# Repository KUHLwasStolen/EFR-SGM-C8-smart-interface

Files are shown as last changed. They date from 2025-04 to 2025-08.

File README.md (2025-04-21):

# EFR-SGM-C8-smart-interface
This project reads the SML-interface of the EFR-SGM-C8 energy meter via an ESP32 and then provides a local web server to show the extracted information.  
This is useful if your meter does not have the "smart" module installed, which net providers like to omit, because... money.  
You can then use the web server to conveniently check you energy usage and adjust the output of your solar storage to not waste any energy or give it away, helping you save even more money.  
Additionally, the API that the website uses to keep itself updated is also available for you to use in other projects.  

**Planned:** In the near future I would also like to add some logging capabilities to the project via an SD card module. This would allow us to display historic data on the website (last 24h/7d/30d/...) which the meter itself collects but does not provide via the IR-interface. Also the data can be used to generate some graphs.  

## Hardware
The project is designed around an ESP32 Mini development board and an TCRT5000 IR sensor.  
Additionally magnets are used to mount the project on the energy-meter.  
The links below are there to show visually you what I mean, not buying recommendations.  

Product | Link
-|-
ESP32 Mini dev board | https://www.az-delivery.de/en/products/esp32-d1-mini-nodemcu-wifi-modul-esp-32-bluetooth-internet-entwicklungsboard-mit-usb-c-anschluss-kompatibel-mit-arduino-und-ko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
TCRT5000 IR sensor | https://www.az-delivery.de/en/products/linienfolger-modul-mit-tcrt5000-und-analog-ausgang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
Round magnets with ~20 mm diameter | no link needed, very generic

Yes, it would also be possible to entirely skip the IR sensor and use only a photo-resistor.  
But I like that the sensor board comes with a potentiometer to easily adjust the sensitivity (which is very important!!!) and that it has an easily accessible mounting point.  

## Installation
### Software
Flashing the ESP with the program should be pretty straightforward:  
1. Clone the repository to your computer
2. Now you need to configure the project. In an ESP-IDF terminal type `idf.py menuconfig`, do your basic setup and go to the menu `YOUR CONFIGURATION` and enter your information there (WiFi config, timezone). To select the correct time zone you can refer to the column on the right of [this](https://github.com/nayarsystems/posix_tz_db/blob/master/zones.csv) list. Make sure that your entries **only** contain the information that their name indicates with **no** additional spaces or other characters before and after your entry, so the ESP can find your WiFi and understand your timezone.
3. Build and flash the project with ESP-IDF.

### Hardware
The hardware setup is also very simple.  
You only need to supply the IR sensor with 3.3V and GND and you need to connect pin 16 of the ESP with the digital out pin of the sensor.  
Now you only need to assemble the 3D-print and mount it on your energy-meter (see below).  

## CAD/3D-models
Currently the only model available is the sensor mount itself. It is already oriented in the intended printing position and does require some supports for the top hook.  
Soon I will add a cover for the mount which also includes an SD card reader spot.  

## Note on the website files
Excuse the weird/lack-of formatting in all of the HTML/CSS/JS files. As they are copied 1-to-1 to the ESP's flash I am trying to save a bit of file size by reducing the readability-formatting to a minimum. If you want, you can let your IDE format the files a bit more readably and then when done editing reduce to tab-size down to one or two spaces again.

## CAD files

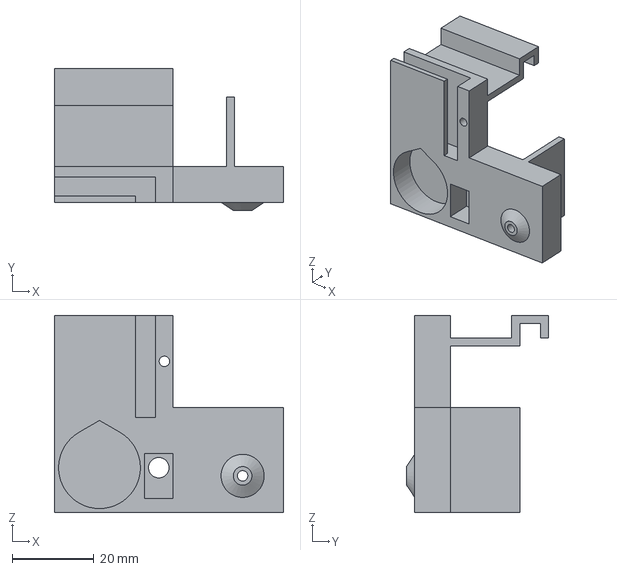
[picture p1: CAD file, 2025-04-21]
cad/exports/irReaderMount.step
56.0 x 34.8 x 48.2 mm

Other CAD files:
cad/sensorMountModels.FCStd

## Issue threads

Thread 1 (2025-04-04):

Meter readings inconsistency

KUHLwasStolen, 2025-04-04:
There is a weird inconsistency in the meter readings.
Not all messages with the correct ID for the meter readings (1.8.0 and 2.8.0) seem to carry the data.
But this is weird, because why send the messages at all then?

A possible explanation would be that my method of reading the data is faulty.
But why are the current power readings consistent and correct then? And why can I even detect the message ID if the data is faulty?

Currently obvious outliers are already filtered, but still some do make it through.
I have to be overseeing something here. Will collect more data logs and try to decipher what makes these wrong messages special.

***Update 1:*** I've now implemented decoding for 1.8.1, 1.8.2, 2.8.1 and 2.8.2 just to see if those values come through consistently. And they indeed do. I assume this means that there is nothing wrong with my physical setup nor my code.

This still doesn't explain why 1.8.0 and 2.8.0 are so weird, but at least we can cope with it now.

Some possible approaches:
1. Calculate the values: $1.8.0 = 1.8.1 + 1.8.2$ and $2.8.0 = 2.8.1 + 2.8.2$
Problem: Depending on your setup this might not work. My example: 1.8.1 and 1.8.2 are sent but 2.8.1 and 2.8.2 are only 0.
2. Let the user chose which of the several collected values are correct and then we can deduce which changes are realistic.
Problem: Requires user intervention, edge cases possible.
3. Collect the last x values and calculate the median over them. This should work as most of the time the correct data is sent. I will implement this and see if it works properly.

***Update 2:*** After implementing a hybrid of approaches 1 and 3 above, the issue is smoothed out a bit, but still not unnoticeable. I have also noticed that values for 1.8.1 and 1.8.2 do in fact not come through perfectly every time, but still better than 1.8.0 alone.

I have noticed that sometimes there are values which theoretically would be correct, but they are received for the wrong ID. This might suggest that there is some kind of bit flip issue going on(?).

For now at least this is my last idea: There is some physical issue going on in the system that sometimes causes a bit flip in the received data and for some reason some messages are easier affected than others (or maybe it's just more noticeable for them as for example wattage values change more often anyways(?)).

My next attempt at solving this will be to add a small resistor in line with the UART RX pin to reduce the noise on there a bit.

***Update 3:*** I have now realized that my implementation of inserting values into the median arrays was faulty and basically deactivated the median. I have now fixed it and, surprise, no faulty values make it through to the UI now...
The only thing that is left to do now is to tune the size of the median arrays in order to balance fault tolerance and responsiveness.
Also, I think we just have to accept that the IR transmission isn't perfect.
(Btw, adding resistors and even diodes to the signal line didn't fix the issues 😅 )

Closed 2025-04-12.

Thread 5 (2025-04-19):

Add smoothing to power draw

KUHLwasStolen, 2025-04-19:
I have noticed that the power values fluctuate quite a bit more than what is shown on the meter's display, which I guess boils down to the same problems as in #1
To fix this also add "median-smoothing" but with a smaller median array because these values need a bit more flexibility than the energy readings.

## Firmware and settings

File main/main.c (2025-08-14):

#include <stdio.h>
#include <stdlib.h>

#include "driver/gpio.h"
#include "driver/uart.h"
#include "soc/uart_channel.h"
#include "esp_log.h"
#include "freertos/FreeRTOS.h"
#include "freertos/task.h"
#include "esp_system.h"

#include "esp_http_server.h"
#include "esp_wifi.h"
#include "esp_event.h"
#include "nvs_flash.h"
#include "esp_netif_sntp.h"
#include "esp_sntp.h"
#include "cJSON.h"

#define WIFI_MAXIMUM_RETRY 5
uint8_t wifi_retries = 0;

#define WIFI_CONNECTED_BIT BIT0
#define WIFI_FAIL_BIT      BIT1

httpd_handle_t serverHandle = NULL;
static EventGroupHandle_t s_wifi_event_group;

void insertFloatAtFirstIndex(float* arr, uint16_t len, float value);
void insertI32AtFirstIndex(int32_t* arr, uint16_t len, int32_t value);
float medianFloat(float* arr, uint16_t len);
int32_t medianI32(int32_t* arr, uint16_t len);
int compareFloat(const void* f1, const void* f2);
int compareI32(const void* i1, const void* i2);
void addFloatToMedianArr(float* arr, uint8_t* sizeCounter, uint8_t sizeMax, float value);
void addI32ToMedianArr(int32_t* arr, uint8_t* sizeCounter, uint8_t sizeMax, int32_t value);

extern const uint8_t indexHtmlFile[] asm("_binary_index_html_start");
extern const uint8_t stylesCssFile[] asm("_binary_styles_css_start");
extern const uint8_t updaterJsFile[] asm("_binary_updater_js_start");
extern const uint8_t settingsHtmlFile[] asm("_binary_settings_html_start");
extern const uint8_t settingsJsFile[] asm("_binary_settings_js_start");
extern const uint8_t faviconSVG_start[] asm("_binary_favicon_svg_start");
extern const uint8_t faviconSVG_end[] asm("_binary_favicon_svg_end");

typedef struct settings_t {
    float importCost;
    float importCostT1;
    float importCostT2;
    float exportCost;
    float exportCostT1;
    float exportCostT2;
    char currency[8];
} settings_t;

int32_t currentPower = 0, currentPowerL1 = 0, currentPowerL2 = 0, currentPowerL3 = 0; // in W
float importOverall = 0.0f, importT1 = 0.0f, importT2 = 0.0f, exportOverall = 0.0f, exportT1 = 0.0f, exportT2 = 0.0f; // in kWh
settings_t settings = {0};

time_t upSince = 0;
char upSinceStr[64] = {};
struct tm timeinfo = {0};

// To decode the SML messages
static void irReaderTask(void* args) {
    const uart_port_t irUART = UART_GPIO16_DIRECT_CHANNEL;
    uart_config_t irConfig = {
        .baud_rate = 9600,
        .data_bits = UART_DATA_8_BITS,
        .parity = UART_PARITY_DISABLE,
        .stop_bits = UART_STOP_BITS_1,
        .flow_ctrl = UART_HW_FLOWCTRL_DISABLE,
        .source_clk = UART_SCLK_DEFAULT,
    };

    ESP_ERROR_CHECK(uart_param_config(irUART, &irConfig));
    ESP_ERROR_CHECK(uart_set_pin(irUART, UART_PIN_NO_CHANGE, 16, UART_PIN_NO_CHANGE, UART_PIN_NO_CHANGE));

    const int uart_buffer_size = 1200 * 2;
    QueueHandle_t uart_queue;

    ESP_ERROR_CHECK(uart_driver_install(irUART, uart_buffer_size, 0, 1, &uart_queue, 0));

    // All of these values are temporary and used by multiple code segments!!!
    // Only use them as placeholders for extracting information from the SML messages!!!
    uint8_t buffer[uart_buffer_size] = {};
    uint16_t readLength = 0;
    uint8_t valueID;
    uint8_t valueLength;
    uint8_t iOffset;
    int32_t tempPower;
    uint64_t meterReadRaw = 0;

    // defines how many values are saved at maximum, for the calculation of the median of the meter readings
    #define BIG_MEDIAN_SIZE_MAX 15
    float importMedianArr[BIG_MEDIAN_SIZE_MAX] = {};
    float importT1MedianArr[BIG_MEDIAN_SIZE_MAX] = {};
    float importT2MedianArr[BIG_MEDIAN_SIZE_MAX] = {};
    float exportMedianArr[BIG_MEDIAN_SIZE_MAX] = {};
    float exportT1MedianArr[BIG_MEDIAN_SIZE_MAX] = {};
    float exportT2MedianArr[BIG_MEDIAN_SIZE_MAX] = {};
    uint8_t importMedianSize = 0, importT1MedianSize = 0, importT2MedianSize = 0, exportMedianSize = 0, exportT1MedianSize = 0, exportT2MedianSize = 0;

    #define SMALL_MEDIAN_SIZE_MAX 5
    int32_t currentPowerMedianArr[SMALL_MEDIAN_SIZE_MAX] = {};
    int32_t currentPowerL1MedianArr[SMALL_MEDIAN_SIZE_MAX] = {};
    int32_t currentPowerL2MedianArr[SMALL_MEDIAN_SIZE_MAX] = {};
    int32_t currentPowerL3MedianArr[SMALL_MEDIAN_SIZE_MAX] = {};
    uint8_t currentPowerMedianSize = 0, currentPowerL1MedianSize = 0, currentPowerL2MedianSize = 0, currentPowerL3MedianSize = 0;

    while(1) {
        readLength = uart_read_bytes(irUART, buffer, uart_buffer_size - 1, 300 / portTICK_PERIOD_MS);

        if(readLength > 0) {
            ESP_LOGI("UART", "New Message (size: %u):", readLength);

            valueID = 0;
            valueLength = 0;

            for(uint16_t i = 0; i < readLength; i++) {
                // printf("%02X ", buffer[i]);

                // Power:           77 07 01 00 10 07 00 FF
                // L1:              77 07 01 00 24 07 00 FF
                // L2:              77 07 01 00 38 07 00 FF
                // L3:              77 07 01 00 4C 07 00 FF
                // Import overall:  77 07 01 00 01 08 00 FF
                // Import T1:       77 07 01 00 01 08 01 FF
                // Import T2:       77 07 01 00 01 08 02 FF
                // Export overall:  77 07 01 00 02 08 00 FF
                // Export T1:       77 07 01 00 02 08 01 FF
                // Export T2:       77 07 01 00 02 08 02 FF
                if(buffer[i] == 0x77) {
                    if(buffer[i+1] == 0x07) {
                        if(buffer[i+2] == 0x01) {
                            if(buffer[i+3] == 0x00) {
                                if(buffer[i+4] == 0x10 || buffer[i+4] == 0x24 || buffer[i+4] == 0x38 || buffer[i+4] == 0x4C) { // power values
                                    if(buffer[i+5] == 0x07) {
                                        if(buffer[i+6] == 0x00) {
                                            if(buffer[i+7] == 0xFF) {
                                                valueID = buffer[i+13];
                                                valueLength = ((uint8_t)(valueID << 4)) >> 4;
                                                tempPower = 0;

                                                if(valueLength == 0) {
                                                    valueID = buffer[i+14];
                                                    valueLength = ((uint8_t)(valueID << 4)) >> 4;
                                                    iOffset = 1;
                                                } else {
                                                    iOffset = 0;
                                                }
                                                
                                                switch(valueLength) {
                                                    case 2:
                                                        tempPower = (int32_t)(int8_t)buffer[i+14+iOffset];
                                                    break;

                                                    case 3:
                                                        tempPower = ((int32_t)((int8_t)buffer[i+14+iOffset]) << 8) + (uint32_t)buffer[i+15+iOffset];
                                                    break;

                                                    case 4:
                                                        tempPower = ((int32_t)((int8_t)buffer[i+14+iOffset]) << 16) + ((uint32_t)(buffer[i+15+iOffset]) << 8) + (uint32_t)buffer[i+16+iOffset];
                                                    break;

                                                    default:
                                                        ESP_LOGW("Parsing", "Unexpected value length: %d", valueLength);
                                                }

                                                switch(buffer[i+4]) {
                                                    case 0x10:
                                                        addI32ToMedianArr(currentPowerMedianArr, &currentPowerMedianSize, SMALL_MEDIAN_SIZE_MAX, tempPower);
                                                        currentPower = medianI32(currentPowerMedianArr, currentPowerMedianSize);
                                                    break;

                                                    case 0x24:
                                                        addI32ToMedianArr(currentPowerL1MedianArr, &currentPowerL1MedianSize, SMALL_MEDIAN_SIZE_MAX, tempPower);
                                                        currentPowerL1 = medianI32(currentPowerL1MedianArr, currentPowerL1MedianSize);
                                                    break;

                                                    case 0x38:
                                                        addI32ToMedianArr(currentPowerL2MedianArr, &currentPowerL2MedianSize, SMALL_MEDIAN_SIZE_MAX, tempPower);
                                                        currentPowerL2 = medianI32(currentPowerL2MedianArr, currentPowerL2MedianSize);
                                                    break;

                                                    case 0x4C:
                                                        addI32ToMedianArr(currentPowerL3MedianArr, &currentPowerL3MedianSize, SMALL_MEDIAN_SIZE_MAX, tempPower);
                                                        currentPowerL3 = medianI32(currentPowerL3MedianArr, currentPowerL3MedianSize);
                                                    break;
                                                }
                                            }
                                        }
                                    }
                                } else if(buffer[i+4] == 0x01 || buffer[i+4] == 0x02) { // import, export
                                    if(buffer[i+5] == 0x08) {
                                        if(buffer[i+6] == 0x00 || buffer[i+6] == 0x01 || buffer[i+6] == 0x02) {
                                            if(buffer[i+7] == 0xFF) {
                                                // search for 0x52FF
                                                for(uint16_t j = i+8; j < i+30; j++) {
                                                    if(buffer[j] == 0x52 && buffer[j+1] == 0xFF) {
                                                        meterReadRaw = 0;

                                                        // search for next message to determine value length
                                                        for(uint8_t k = 2; k < 6; k++) {
                                                            if(buffer[j+3+k] == 0x01 && buffer[j+3+k+1] == 0x77) {
                                                                if(k < 3) break;

                                                                // now fill meterReadRaw according to length
                                                                for(uint8_t l = 0; l < k; l++) {
                                                                    meterReadRaw += ((uint64_t)buffer[j+3+l]) << ((k-1-l)*8);
                                                                }

                                                                switch(buffer[i+4]) {
                                                                    case 0x01: // import
                                                                        switch(buffer[i+6]) {
                                                                            case 0x00:
                                                                                addFloatToMedianArr(importMedianArr, &importMedianSize, BIG_MEDIAN_SIZE_MAX, meterReadRaw / 10000.0f);
                                                                                importOverall = medianFloat(importMedianArr, importMedianSize);
                                                                            break;

                                                                            case 0x01:
                                                                                addFloatToMedianArr(importT1MedianArr, &importT1MedianSize, BIG_MEDIAN_SIZE_MAX, meterReadRaw / 10000.0f);
                                                                                importT1 = medianFloat(importT1MedianArr, importT1MedianSize);
                                                                                if(importT1 > 1 && importT2 > 1) addFloatToMedianArr(importMedianArr, &importMedianSize, BIG_MEDIAN_SIZE_MAX, importT1 + importT2);
                                                                            break;

                                                                            case 0x02:
                                                                                addFloatToMedianArr(importT2MedianArr, &importT2MedianSize, BIG_MEDIAN_SIZE_MAX, meterReadRaw / 10000.0f);
                                                                                importT2 = medianFloat(importT2MedianArr, importT2MedianSize);
                                                                                if(importT1 > 1 && importT2 > 1) addFloatToMedianArr(importMedianArr, &importMedianSize, BIG_MEDIAN_SIZE_MAX, importT1 + importT2);
                                                                            break;
                                                                        }
                                                                    break;

                                                                    case 0x02: // export
                                                                        switch(buffer[i+6]) {
                                                                            case 0x00:
                                                                                addFloatToMedianArr(exportMedianArr, &exportMedianSize, BIG_MEDIAN_SIZE_MAX, meterReadRaw / 10000.0f);
                                                                                exportOverall = medianFloat(exportMedianArr, exportMedianSize);
                                                                            break;

                                                                            case 0x01:
                                                                                addFloatToMedianArr(exportT1MedianArr, &exportT1MedianSize, BIG_MEDIAN_SIZE_MAX, meterReadRaw / 10000.0f);
                                                                                exportT1 = medianFloat(exportT1MedianArr, exportT1MedianSize);
                                                                                if(exportT1 > 1 && exportT2 > 1) addFloatToMedianArr(exportMedianArr, &exportMedianSize, BIG_MEDIAN_SIZE_MAX, exportT1 + exportT2);
                                                                            break;

                                                                            case 0x02:
                                                                                addFloatToMedianArr(exportT2MedianArr, &exportT2MedianSize, BIG_MEDIAN_SIZE_MAX, meterReadRaw / 10000.0f);
                                                                                exportT2 = medianFloat(exportT2MedianArr, exportT2MedianSize);
                                                                                if(exportT1 > 1 && exportT2 > 1) addFloatToMedianArr(exportMedianArr, &exportMedianSize, BIG_MEDIAN_SIZE_MAX, exportT1 + exportT2);
                                                                            break;
                                                                        }
                                                                    break;
                                                                }

                                                                break;
                                                            }
                                                        }

                                                        break;
                                                    }
                                                }
                                            }
                                        }
                                    }
                                }
                            }
                        }
                    }
                }
            }
            // printf("\n\n");

            ESP_LOGI("Power", "Overall: %ld  L1: %ld  L2: %ld  L3: %ld", currentPower, currentPowerL1, currentPowerL2, currentPowerL3);
            ESP_LOGI("Meter readings", "Import: %.3f  T1: %.3f  T2: %.3f  Export: %.3f  T1: %.3f  T2: %.3f", importOverall, importT1, importT2, exportOverall, exportT1, exportT2);

            ESP_ERROR_CHECK(uart_flush_input(irUART));
        }
    }
}
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
void app_main(void) {
    if(strcmp(CONFIG_YOUR_AP_SSID, "MyExampleAccessPoint1234") == 0) ESP_LOGW("CONFIG", "Your AP SSID matches the default, make sure your config is correct (see README.md).");
    if(strcmp(CONFIG_YOUR_AP_PASSWORD, "MySuperSecureExamplePassword1234") == 0) ESP_LOGW("CONFIG", "Your AP password matches the default, make sure your config is correct (see README.md).");
    if(strcmp(CONFIG_YOUR_TIME_ZONE, "UTC0") == 0) ESP_LOGW("CONFIG", "Your timezone matches the default, if you want to use UTC0 there is nothing to worry about, if need a different timezone check your config (see README.md).");

    //Initialize NVS
    esp_err_t ret = nvs_flash_init();
    if (ret == ESP_ERR_NVS_NO_FREE_PAGES || ret == ESP_ERR_NVS_NEW_VERSION_FOUND) {
      ESP_ERROR_CHECK(nvs_flash_erase());
      ret = nvs_flash_init();
    }
    ESP_ERROR_CHECK(ret);

    // Load settings from NVS
    nvs_handle_t settingsHandle;
    ret = nvs_open("siteSettings", NVS_READONLY, &settingsHandle);
    if(ret != ESP_OK) {
        ESP_LOGW("NVS settings", "Could not load settings from NVS. Not a problem if no settings have been saved yet.");
    } else {
        ESP_LOGI("NVS settings", "Loading settings...");
        uint32_t costsRaw = 0;

        ret = nvs_get_u32(settingsHandle, "importCost", &costsRaw);
        if(ret == ESP_OK) settings.importCost = ((float)costsRaw) / 100.0f;
        ret = nvs_get_u32(settingsHandle, "importCostT1", &costsRaw);
        if(ret == ESP_OK) settings.importCostT1 = ((float)costsRaw) / 100.0f;
        ret = nvs_get_u32(settingsHandle, "importCostT2", &costsRaw);
        if(ret == ESP_OK) settings.importCostT2 = ((float)costsRaw) / 100.0f;
        ret = nvs_get_u32(settingsHandle, "exportCost", &costsRaw);
        if(ret == ESP_OK) settings.exportCost = ((float)costsRaw) / 100.0f;
        ret = nvs_get_u32(settingsHandle, "exportCostT1", &costsRaw);
        if(ret == ESP_OK) settings.exportCostT1 = ((float)costsRaw) / 100.0f;
        ret = nvs_get_u32(settingsHandle, "exportCostT2", &costsRaw);
        if(ret == ESP_OK) settings.exportCostT2 = ((float)costsRaw) / 100.0f;

        size_t currencySize;
        ret = nvs_get_str(settingsHandle, "currency", NULL, &currencySize);
        if(ret == ESP_OK && !(currencySize > (size_t)8)) nvs_get_str(settingsHandle, "currency", settings.currency, &currencySize);

        nvs_close(settingsHandle);
    }

    xTaskCreatePinnedToCore(irReaderTask, "irReaderTask", 20000, NULL, 10, NULL, 1);
    xTaskCreatePinnedToCore(httpServerTask, "httpServerTask", 10000, NULL, 10, NULL, 0);
}


// ### Array handling helpers to calculate median for 1.8.0 and 2.8.0
// shifts everything one index up and then inserts the value at 0
void insertFloatAtFirstIndex(float* arr, uint16_t len, float value) {
    for(int32_t i = len - 2; i >= 0; i--) arr[i+1] = arr[i];

    arr[0] = value;
}

void insertI32AtFirstIndex(int32_t* arr, uint16_t len, int32_t value) {
    for(int32_t i = len - 2; i >= 0; i--) arr[i+1] = arr[i];

    arr[0] = value;
}

// takes an unsorted array and calculates the median over it
float medianFloat(float* arr, uint16_t len) {
    // we need to sort the array to calculate the median, but we leave the input array untouched
    float sortArr[len] = {};
    memcpy(sortArr, arr, len * sizeof(float));
    qsort(sortArr, len, sizeof(float), compareFloat);

    if(len % 2) { // if len is odd, only need to evaluate one element
        return sortArr[(len/2)];
    } else { // if len is even, need to calculate average over middle two elemets
        return (sortArr[(len/2) - 1] + sortArr[(len/2)]) / 2.0f;
    }
}

int32_t medianI32(int32_t* arr, uint16_t len) {
    // we need to sort the array to calculate the median, but we leave the input array untouched
    int32_t sortArr[len] = {};
    memcpy(sortArr, arr, len * sizeof(int32_t));
    qsort(sortArr, len, sizeof(int32_t), compareI32);

    if(len % 2) { // if len is odd, only need to evaluate one element
        return sortArr[(len/2)];
    } else { // if len is even, need to calculate average over middle two elemets
        return (sortArr[(len/2) - 1] + sortArr[(len/2)]) / 2;
    }
}

// used for the sorting in median calculation
int compareFloat(const void* f1, const void* f2) {
    float float1 = *((float*)f1);
    float float2 = *((float*)f2);

    if(float1 > float2) return 1;
    if(float2 > float1) return -1;
    return 0;
}

int compareI32(const void* i1, const void* i2) {
    int32_t int1 = *((int32_t*)i1);
    int32_t int2 = *((int32_t*)i2);

    if(int1 > int2) return 1;
    if(int2 > int1) return -1;
    return 0;
}

void addFloatToMedianArr(float* arr, uint8_t* sizeCounter, uint8_t sizeMax,float value) {
    insertFloatAtFirstIndex(arr, *sizeCounter, value);
    if(*sizeCounter < sizeMax) (*sizeCounter)++;
}

void addI32ToMedianArr(int32_t* arr, uint8_t* sizeCounter, uint8_t sizeMax, int32_t value) {
    insertI32AtFirstIndex(arr, *sizeCounter, value);
    if(*sizeCounter < sizeMax) (*sizeCounter)++;
}

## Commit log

2025-04-04 separated website into 3 files, lots of bug fixes (but not perfect yet)
    [main.c]
2025-04-06 implemented a hybrid of approches 1, 3 to solve inconsistency issue (see #1), still not perfect, adapted website favicon to svg format (closes #2)
    [main.c]
2025-04-08 add first prototype version of mount, extend README a bit further
    [irReaderMount.step, sensorMountModels.FCStd]
2025-04-12 fixed the median implementation, closes #1
    [main.c]
2025-04-21 sensor mount redesign, part of #3
    [irReaderMount.step, sensorMountModels.FCStd]
2025-04-22 added smoothing to power draw metrics, closes #5 , fixed a config error that made some browsers fail to access the settings site
    [main.c]
2025-05-03 fix dimensions a bit
    [sensorMountModels.FCStd]
2025-08-14 patch weird "length zero" power value
